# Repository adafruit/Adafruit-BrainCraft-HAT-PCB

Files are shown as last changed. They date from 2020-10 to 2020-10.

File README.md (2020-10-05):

## Adafruit Adafruit BrainCraft HAT - Machine Learning for Raspberry Pi 4 PCB

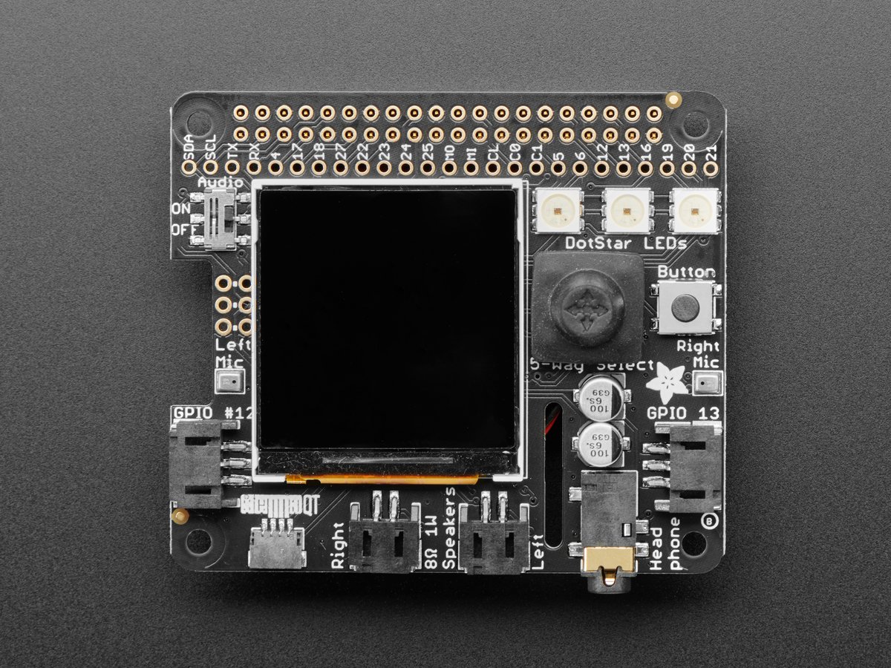
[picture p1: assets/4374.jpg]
<a href="http://www.adafruit.com/products/4374"><br/>
Click here to purchase one from the Adafruit shop</a>

PCB files for the Adafruit BrainCraft HAT - Machine Learning for Raspberry Pi 4. 

Format is EagleCAD schematic and board layout
* https://www.adafruit.com/product/4374

### Description

The idea behind the BrainCraft HAT is that you’d be able to “craft brains” for Machine Learning on the EDGE, with Microcontrollers & Microcomputers. On ASK AN ENGINEER, our founder & engineer chatted with Pete Warden, the technical lead of the mobile, embedded TensorFlow Group on Google’s Brain team about what would be ideal for a board like this.

And here’s what we designed! The BrainCraft HAT has a 240×240 TFT IPS display for inference output, slots for camera connector cable for imaging projects, a 5 way joystick and button for UI input, left and right microphones, stereo headphone out, stereo 1 W speaker out, three RGB DotStar LEDs, two 3 pin STEMMA connectors on PWM pins so they can drive NeoPixels or servos, and Grove/STEMMA/Qwiic I2C port. This will let people build a wide range of audio/video AI projects while also allowing easy plug-in of sensors and robotics!

A controllable mini fan attaches to the bottom, and can be used to keep your Pi cool while doing intense AI inference calculations. **Most importantly, there’s an On/Off switch that will completely disable the audio codec, so that when it's off there’s no way it's listening to you.**

**Features:**
 * **1.54" IPS TFT** display with 240x240 resolution that can show text or video
 * **Stereo speaker ports for audio playback** - either text-to-speech, alerts or for creating a voice assistant.
 * **Stereo headphone out** for audio playback through a stereo system, headphones, or powered speakers.
 * **Stereo microphone input** - perfect for making your very own smart home assistants
 * **Two 3-pin JST STEMMA connectors** that can be used to [connect more buttons](https://www.adafruit.com/product/4431), [a relay](https://www.adafruit.com/product/4409), or [even some NeoPixels!](https://www.adafruit.com/product/3919)
 * **[STEMMA QT plug-and-play I2C port](https://learn.adafruit.com/introducing-adafruit-stemma-qt)**, can be used with [any of our 50+ I2C STEMMA QT boards](https://www.adafruit.com/category/620), or can be used to [connect to Grove I2C devices with an adapter cable](https://www.adafruit.com/product/4528).
 * **5-Way Joystick + Button** for user interface and control.
 * **Three RGB DotStar LEDs** for colorful LED feedback.

The STEMMA QT port means you can attach heat image sensors like the [Panasonic Grid-EYE](https://www.adafruit.com/product/3538) or [MLX90640](https://www.adafruit.com/?q=mlx90640&sort=BestMatch). Heat-Sensitive cameras can be used as a person detector, even in the dark! An external accelerometer can be attached for gesture or vibration sensing such as machinery/industrial predictive maintenance projects

### License

Adafruit invests time and resources providing this open source design, please support Adafruit and open-source hardware by purchasing products from [Adafruit](https://www.adafruit.com)!

Designed by Limor Fried/Ladyada for Adafruit Industries.

Creative Commons Attribution/Share-Alike, all text above must be included in any redistribution. 
See license.txt for additional details.

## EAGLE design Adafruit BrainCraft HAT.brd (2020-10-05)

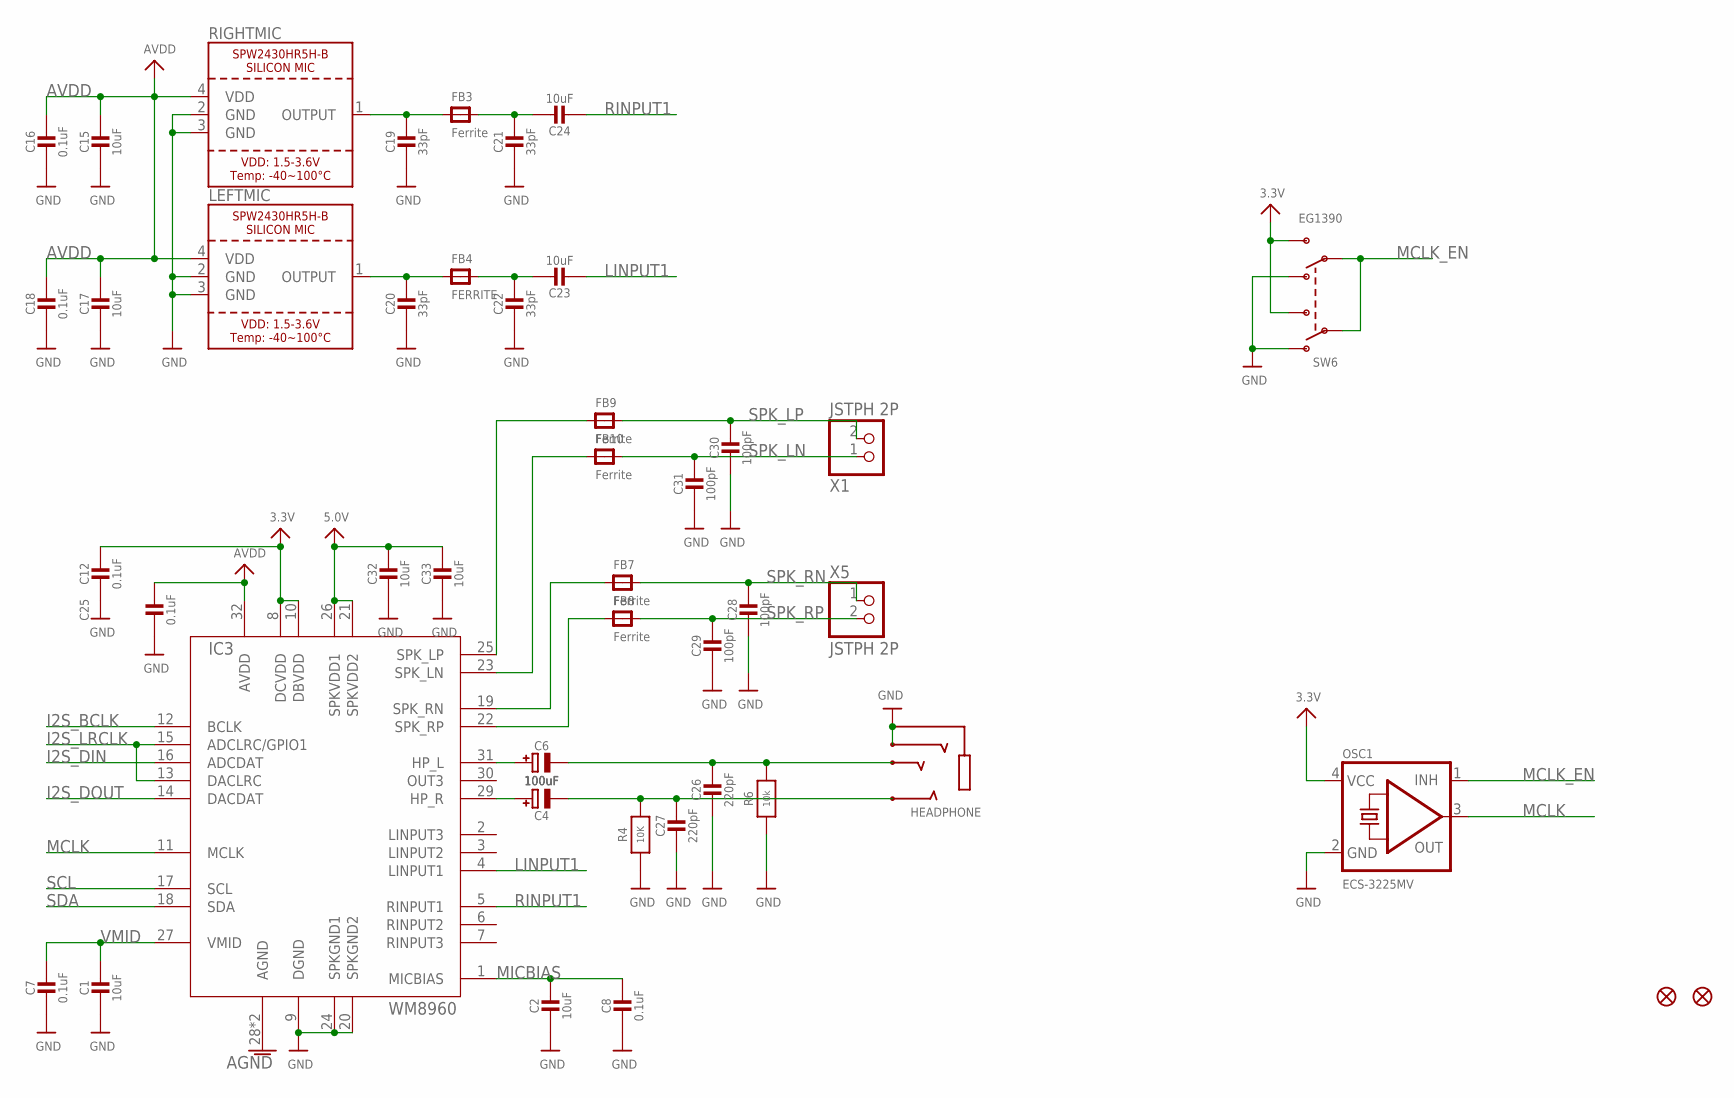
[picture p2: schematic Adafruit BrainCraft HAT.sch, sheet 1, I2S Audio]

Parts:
C1, C2, C15, C17, C23, C24, C32, C33: 10uF; 0805-NO
C4, C6: 100uF; PANASONIC_C
C7, C8, C12, C16, C18, C25: 0.1uF; 0603-NO
C19, C20, C21, C22: 33pF; 0603-NO
C26, C27: 220pF; 0603-NO
C28, C29, C30, C31: 100pF; 0603-NO
FB3, FB7, FB8, FB9, FB10: Ferrite; 0805-NO
FB4: FERRITE; 0805-NO
FID1, FID2: FIDUCIAL_1MM
HEADPHONE: AUDIO_3.5MMJACK_4POL; 4UCONN_18510
IC3: WM8960; QFN32_5MM
LEFTMIC: SPW2430HR5H-B
OSC1: ECS-3225MV; OSC_3.2X2.5MM
R4: 10K; 0603-NO
R6: 10k; 0603-NO
RIGHTMIC: SPW2430HR5H-B
SW6: EG1390
X1, X5: JSTPH 2P; JSTPH2

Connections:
3.3V: C12.1, IC3.8 (DCVDD), IC3.10 (DBVDD), OSC1.4 (VCC), SW6.S1, SW6.S2; also elsewhere on the board
5.0V: C32.1, C33.1, IC3.21 (SPKVDD2), IC3.26 (SPKVDD1); also elsewhere on the board
AGND: IC3.28 (AGND), IC3.33 (AGND); also elsewhere on the board
AVDD: C15.1, C16.1, C17.1, C18.1, C25.1, IC3.32 (AVDD), LEFTMIC.4 (VDD), RIGHTMIC.4 (VDD); also elsewhere on the board
GND: C1.2, C2.2, C7.2, C8.2, C12.2, C15.2, C16.2, C17.2, C18.2, C19.2, C20.2, C21.2, C22.2, C25.2, C26.2, C27.2, C28.2, C29.2, C30.2, C31.2, C32.2, C33.2, HEADPHONE.1-GND (TIP), HEADPHONE.4-INNER_SLEEVE (RING1), IC3.9 (DGND), IC3.20 (SPKGND2), IC3.24 (SPKGND1), LEFTMIC.2 (GND), LEFTMIC.3 (GND), OSC1.2 (GND), R4.1, R6.1, RIGHTMIC.2 (GND), RIGHTMIC.3 (GND), SW6.O1, SW6.O2; also elsewhere on the board
I2S_BCLK: IC3.12 (BCLK); also elsewhere on the board
I2S_DIN: IC3.16 (ADCDAT); also elsewhere on the board
I2S_DOUT: IC3.14 (DACDAT); also elsewhere on the board
I2S_LRCLK: IC3.13 (DACLRC), IC3.15 (ADCLRC/GPIO1); also elsewhere on the board
LINPUT1: C23.2, IC3.4 (LINPUT1)
MCLK: IC3.11 (MCLK), OSC1.3 (OUT)
MCLK_EN: OSC1.1 (INH), SW6.P1, SW6.P2
MICBIAS: C2.1, C8.1, IC3.1 (MICBIAS)
unnamed: FB7.1, IC3.19 (SPK_RN)
unnamed: FB8.1, IC3.22 (SPK_RP)
unnamed: C6.+, IC3.31 (HP_L)
unnamed: C4.+, IC3.29 (HP_R)
unnamed: C4.-, C27.1, HEADPHONE.3-OUTER_SLEEVE (RING2), R4.2
unnamed: C6.-, C26.1, HEADPHONE.2-TIP (RING3), R6.2
unnamed: C19.1, FB3.1, RIGHTMIC.1 (OUTPUT)
unnamed: C20.1, FB4.1, LEFTMIC.1 (OUTPUT)
unnamed: C21.1, C24.1, FB3.2
unnamed: C22.1, C23.1, FB4.2
unnamed: FB9.1, IC3.25 (SPK_LP)
unnamed: FB10.1, IC3.23 (SPK_LN)
RINPUT1: C24.2, IC3.5 (RINPUT1)
SCL: IC3.17 (SCL); also elsewhere on the board
SDA: IC3.18 (SDA); also elsewhere on the board
SPK_LN: C31.1, FB10.2, X1.1
SPK_LP: C30.1, FB9.2, X1.2
SPK_RN: C28.1, FB7.2, X5.1
SPK_RP: C29.1, FB8.2, X5.2
VMID: C1.1, C7.1, IC3.27 (VMID)

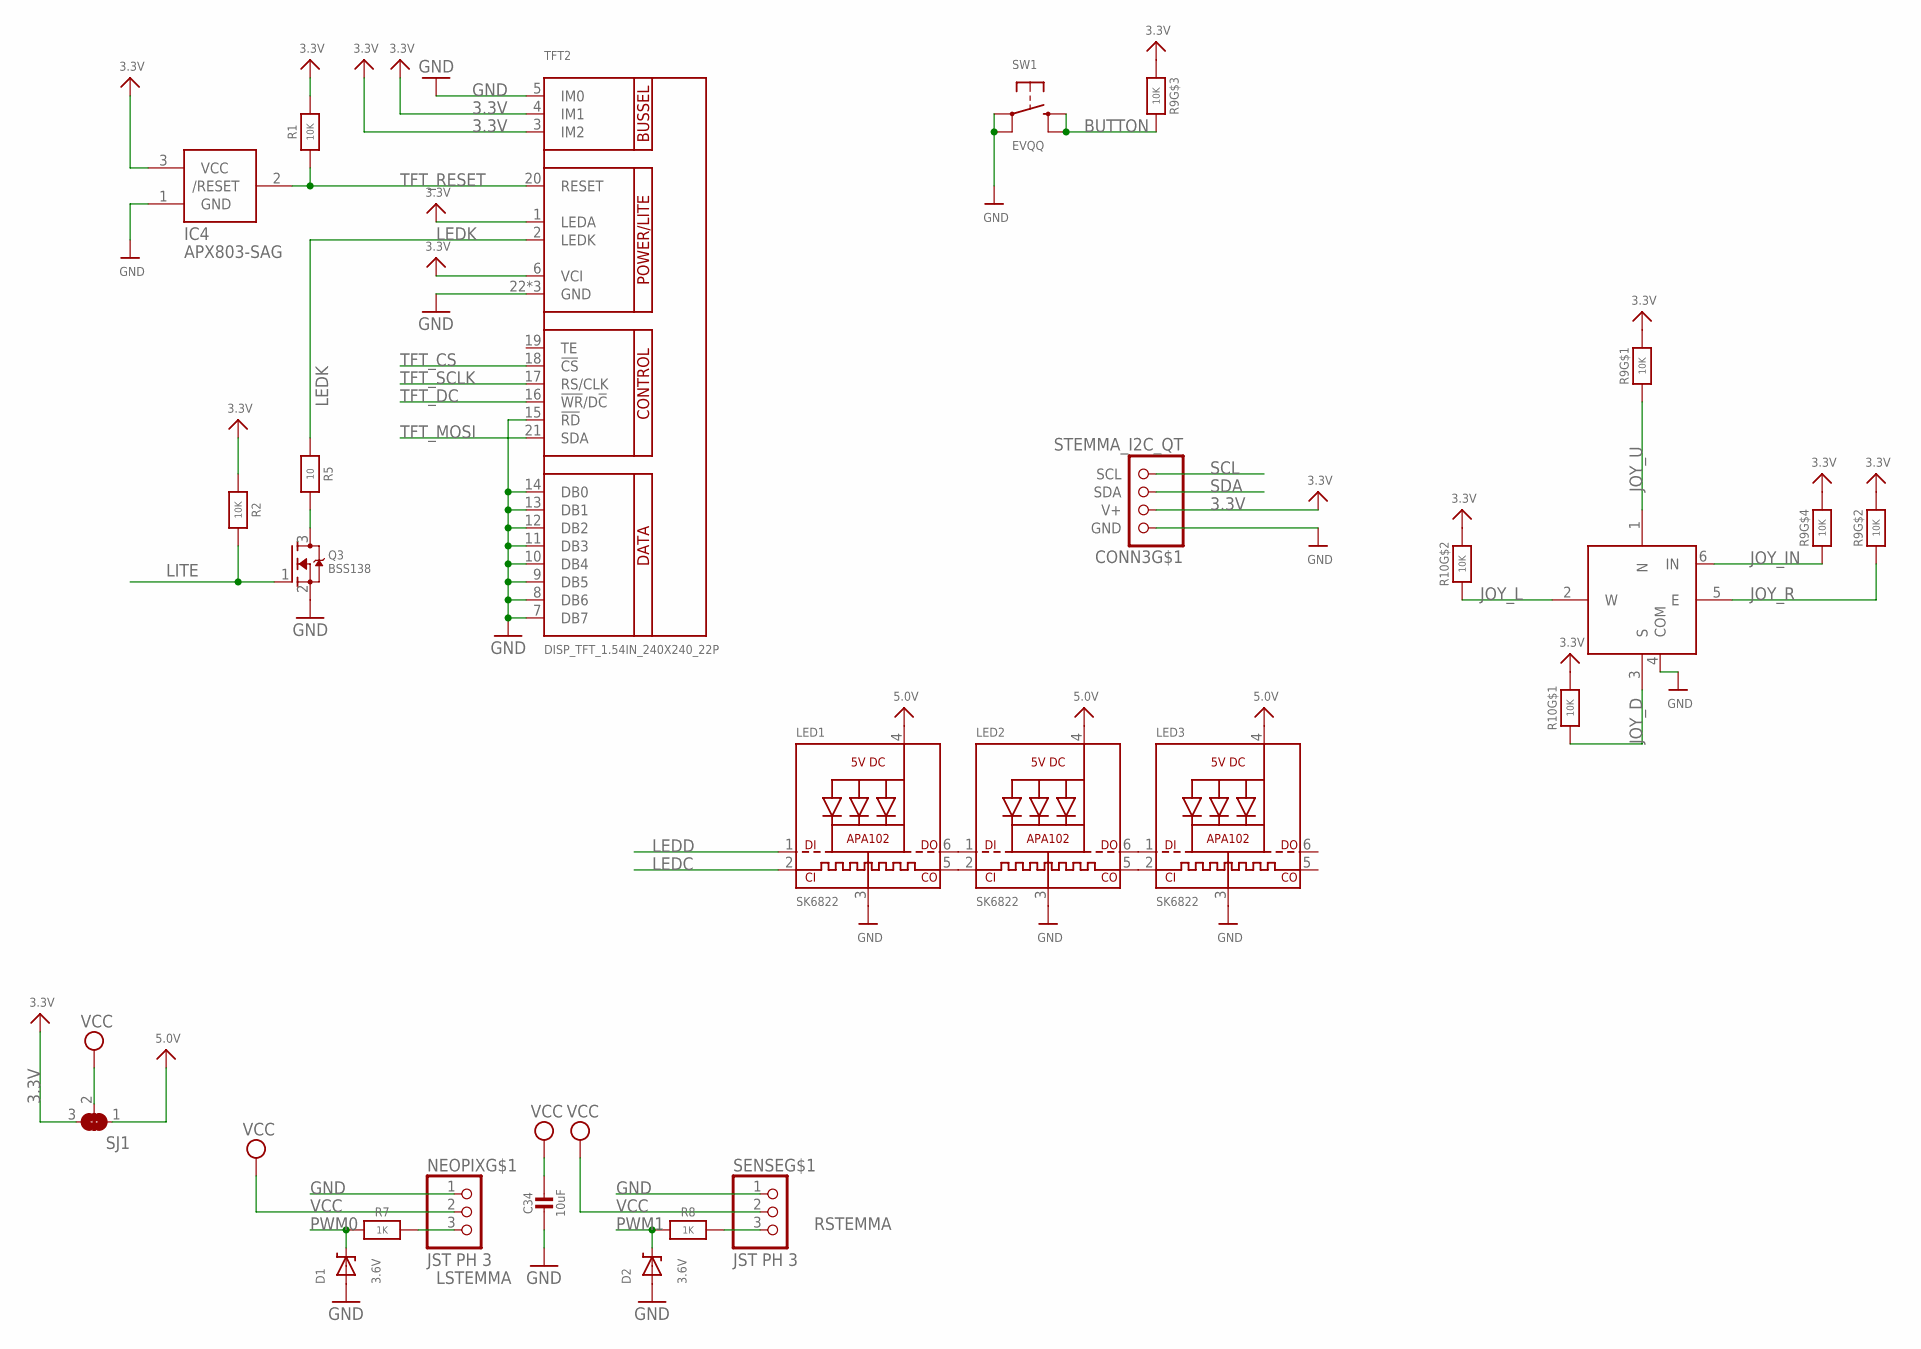
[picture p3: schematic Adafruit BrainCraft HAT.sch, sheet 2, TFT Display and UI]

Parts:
C34: 10uF; 0805-NO
CONN3: STEMMA_I2C_QT; JST_SH4
D1, D2: 3.6V; SOD-323
IC4: APX803-SAG; SOT23
LED1, LED2, LED3: SK6822; APA102
NEOPIX: JST PH 3; JSTPH3
Q3: BSS138; SOT23-WIDE
R1, R2: 10K; 0603-NO
R5: 10; 0603-NO
R7, R8: 1K; 0603-NO
R9, R10: 10K; RESPACK_4X0603
SENSE: JST PH 3; JSTPH3
SJ1: SOLDERJUMPER_2WAY; SOLDERJUMPER_2WAY_OPEN_NOPASTE
SW1: EVQQ; EVQ-Q2_SMALLER
SW5: NAVSWITCHSKQUABAUE010; SKQUBAE010
TFT2: DISP_TFT_1.54IN_240X240_22P; TFT_1.54IN_240X240_22PIN

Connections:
3.3V: CONN3.2 (V+), IC4.3 (VCC), R1.2, R2.2, R9.5 (2), R9.6 (2), R9.7 (2), R9.8 (2), R10.7 (2), R10.8 (2), SJ1.3, TFT2.1 (LEDA), TFT2.3 (IM2), TFT2.4 (IM1), TFT2.6 (VCI); also elsewhere on the board
5.0V: LED1.4 (VDD), LED2.4 (VDD), LED3.4 (VDD), SJ1.1; also elsewhere on the board
BUTTON: R9.3 (1), SW1.B (S), SW1.B' (S1); also elsewhere on the board
GND: C34.2, CONN3.1 (GND), D1.A, D2.A, IC4.1 (GND), LED1.3 (GND), LED2.3 (GND), LED3.3 (GND), NEOPIX.1, Q3.2 (S), SENSE.1, SW1.A, SW1.A' (P1), SW5.4 (COM), TFT2.5 (IM0), TFT2.7 (DB7), TFT2.8 (DB6), TFT2.9 (DB5), TFT2.10 (DB4), TFT2.11 (DB3), TFT2.12 (DB2), TFT2.13 (DB1), TFT2.14 (DB0), TFT2.15 (!RD), TFT2.22 (GND), TFT2.SUPPORT1 (GND), TFT2.SUPPORT2 (GND); also elsewhere on the board
JOY_D: R10.1, SW5.3 (S); also elsewhere on the board
JOY_IN: R9.4 (1), SW5.6 (IN); also elsewhere on the board
JOY_L: R10.2 (1), SW5.2 (W); also elsewhere on the board
JOY_R: R9.2 (1), SW5.5 (E); also elsewhere on the board
JOY_U: R9.1, SW5.1 (N); also elsewhere on the board
LEDC: LED1.2 (CKI); also elsewhere on the board
LEDD: LED1.1 (DI); also elsewhere on the board
LEDK: R5.2, TFT2.2 (LEDK)
LITE: Q3.1 (G), R2.1; also elsewhere on the board
LSTEMMA: NEOPIX.3, R7.1
unnamed: Q3.3 (D), R5.1
unnamed: LED1.6 (DO), LED2.1 (DI)
unnamed: LED1.5 (CKO), LED2.2 (CKI)
unnamed: LED2.6 (DO), LED3.1 (DI)
unnamed: LED2.5 (CKO), LED3.2 (CKI)
PWM0: D1.C, R7.2; also elsewhere on the board
PWM1: D2.C, R8.2; also elsewhere on the board
RSTEMMA: R8.1, SENSE.3
SCL: CONN3.4 (SCL); also elsewhere on the board
SDA: CONN3.3 (SDA); also elsewhere on the board
TFT_CS: TFT2.18 (!CS); also elsewhere on the board
TFT_DC: TFT2.16 (!WR!/D!C); also elsewhere on the board
TFT_MOSI: TFT2.21 (SDA); also elsewhere on the board
TFT_RESET: IC4.2 (/RESET), R1.1, TFT2.20 (RESET)
TFT_SCLK: TFT2.17 (RS/CLK); also elsewhere on the board
VCC: C34.1, NEOPIX.2, SENSE.2, SJ1.2

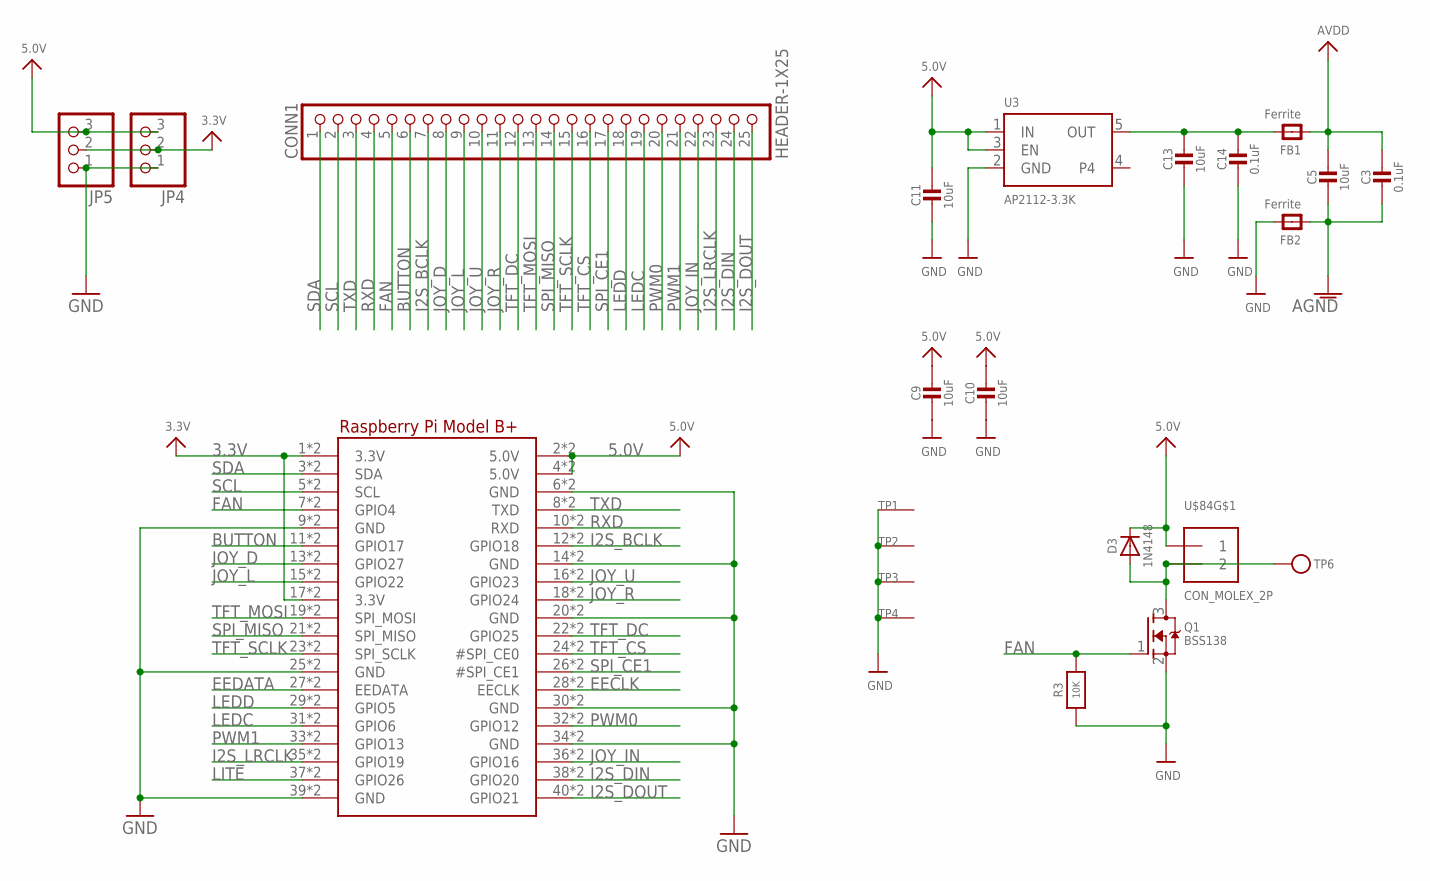
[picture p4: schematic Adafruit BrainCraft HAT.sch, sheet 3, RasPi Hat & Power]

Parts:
C3, C14: 0.1uF; 0603-NO
C5, C9, C10, C11, C13: 10uF; 0805-NO
CONN1: HEADER-1X25; 1X25_ROUND_70MIL
D3: 1N4148; SOD-323
FB1, FB2: Ferrite; 0805
JP4, JP5: HEADER-1X376MIL; 1X03_ROUND_76
Q1: BSS138; SOT23-WIDE
R3: 10K; 0603-NO
RPI1: RASPBERRYPI_BPLUS_HAT_SMTTHM_SLOTS; PI_HAT_SMTTHM_SLOTS
TP1, TP2, TP3, TP4: SEWTAP_SMTNUTM3; SMT_NUT_3MM
TP6: TESTPOINTROUND2MM; TESTPOINT_ROUND_2MM
U3: AP2112-3.3K; SOT23-5
U$84: CON_MOLEX_2P; 53398-0271

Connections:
3.3V: JP4.2, JP5.2, RPI1.1 (3.3V), RPI1.17 (3.3V), RPI1.S1 (3.3V), RPI1.S17 (3.3V); also elsewhere on the board
5.0V: C9.1, C10.1, C11.1, D3.C, JP4.3, JP5.3, RPI1.2 (5.0V), RPI1.4 (5.0V), RPI1.S2 (5.0V), RPI1.S4 (5.0V), U3.1 (IN), U3.3 (EN), U$84.1; also elsewhere on the board
AGND: C3.2, C5.2, FB2.1; also elsewhere on the board
AVDD: C3.1, C5.1, FB1.1; also elsewhere on the board
BUTTON: CONN1.6, RPI1.11 (GPIO17), RPI1.S11 (GPIO17); also elsewhere on the board
EECLK: RPI1.28 (EECLK), RPI1.S28 (EECLK)
EEDATA: RPI1.27 (EEDATA), RPI1.S27 (EEDATA)
FAN: CONN1.5, Q1.1 (G), R3.1, RPI1.7 (GPIO4), RPI1.S7 (GPIO4)
GND: C9.2, C10.2, C11.2, C13.2, C14.2, FB2.2, JP4.1, JP5.1, Q1.2 (S), R3.2, RPI1.6 (GND), RPI1.9 (GND), RPI1.14 (GND), RPI1.20 (GND), RPI1.25 (GND), RPI1.30 (GND), RPI1.34 (GND), RPI1.39 (GND), RPI1.S6 (GND), RPI1.S9 (GND), RPI1.S14 (GND), RPI1.S20 (GND), RPI1.S25 (GND), RPI1.S30 (GND), RPI1.S34 (GND), RPI1.S39 (GND), TP1.P$1, TP2.P$1, TP3.P$1, TP4.P$1, U3.2 (GND); also elsewhere on the board
I2S_BCLK: CONN1.7, RPI1.12 (GPIO18), RPI1.S12 (GPIO18); also elsewhere on the board
I2S_DIN: CONN1.24, RPI1.38 (GPIO20), RPI1.S38 (GPIO20); also elsewhere on the board
I2S_DOUT: CONN1.25, RPI1.40 (GPIO21), RPI1.S40 (GPIO21); also elsewhere on the board
I2S_LRCLK: CONN1.23, RPI1.35 (GPIO19), RPI1.S35 (GPIO19); also elsewhere on the board
JOY_D: CONN1.8, RPI1.13 (GPIO27), RPI1.S13 (GPIO27); also elsewhere on the board
JOY_IN: CONN1.22, RPI1.36 (GPIO16), RPI1.S36 (GPIO16); also elsewhere on the board
JOY_L: CONN1.9, RPI1.15 (GPIO22), RPI1.S15 (GPIO22); also elsewhere on the board
JOY_R: CONN1.11, RPI1.18 (GPIO24), RPI1.S18 (GPIO24); also elsewhere on the board
JOY_U: CONN1.10, RPI1.16 (GPIO23), RPI1.S16 (GPIO23); also elsewhere on the board
LEDC: CONN1.19, RPI1.31 (GPIO6), RPI1.S31 (GPIO6); also elsewhere on the board
LEDD: CONN1.18, RPI1.29 (GPIO5), RPI1.S29 (GPIO5); also elsewhere on the board
LITE: RPI1.37 (GPIO26), RPI1.S37 (GPIO26); also elsewhere on the board
unnamed: D3.A, Q1.3 (D), TP6.P$1, U$84.2
OUT: C13.1, C14.1, FB1.2, U3.5 (OUT)
PWM0: CONN1.20, RPI1.32 (GPIO12), RPI1.S32 (GPIO12); also elsewhere on the board
PWM1: CONN1.21, RPI1.33 (GPIO13), RPI1.S33 (GPIO13); also elsewhere on the board
RXD: CONN1.4, RPI1.10 (RXD), RPI1.S10 (RXD)
SCL: CONN1.2, RPI1.5 (SCL), RPI1.S5 (SCL); also elsewhere on the board
SDA: CONN1.1, RPI1.3 (SDA), RPI1.S3 (SDA); also elsewhere on the board
SPI_CE1: CONN1.17, RPI1.26 (#SPI_CE1), RPI1.S26 (#SPI_CE1)
SPI_MISO: CONN1.14, RPI1.21 (SPI_MISO), RPI1.S21 (SPI_MISO)
TFT_CS: CONN1.16, RPI1.24 (#SPI_CE0), RPI1.S24 (#SPI_CE0); also elsewhere on the board
TFT_DC: CONN1.12, RPI1.22 (GPIO25), RPI1.S22 (GPIO25); also elsewhere on the board
TFT_MOSI: CONN1.13, RPI1.19 (SPI_MOSI), RPI1.S19 (SPI_MOSI); also elsewhere on the board
TFT_SCLK: CONN1.15, RPI1.23 (SPI_SCLK), RPI1.S23 (SPI_SCLK); also elsewhere on the board
TXD: CONN1.3, RPI1.8 (TXD), RPI1.S8 (TXD)

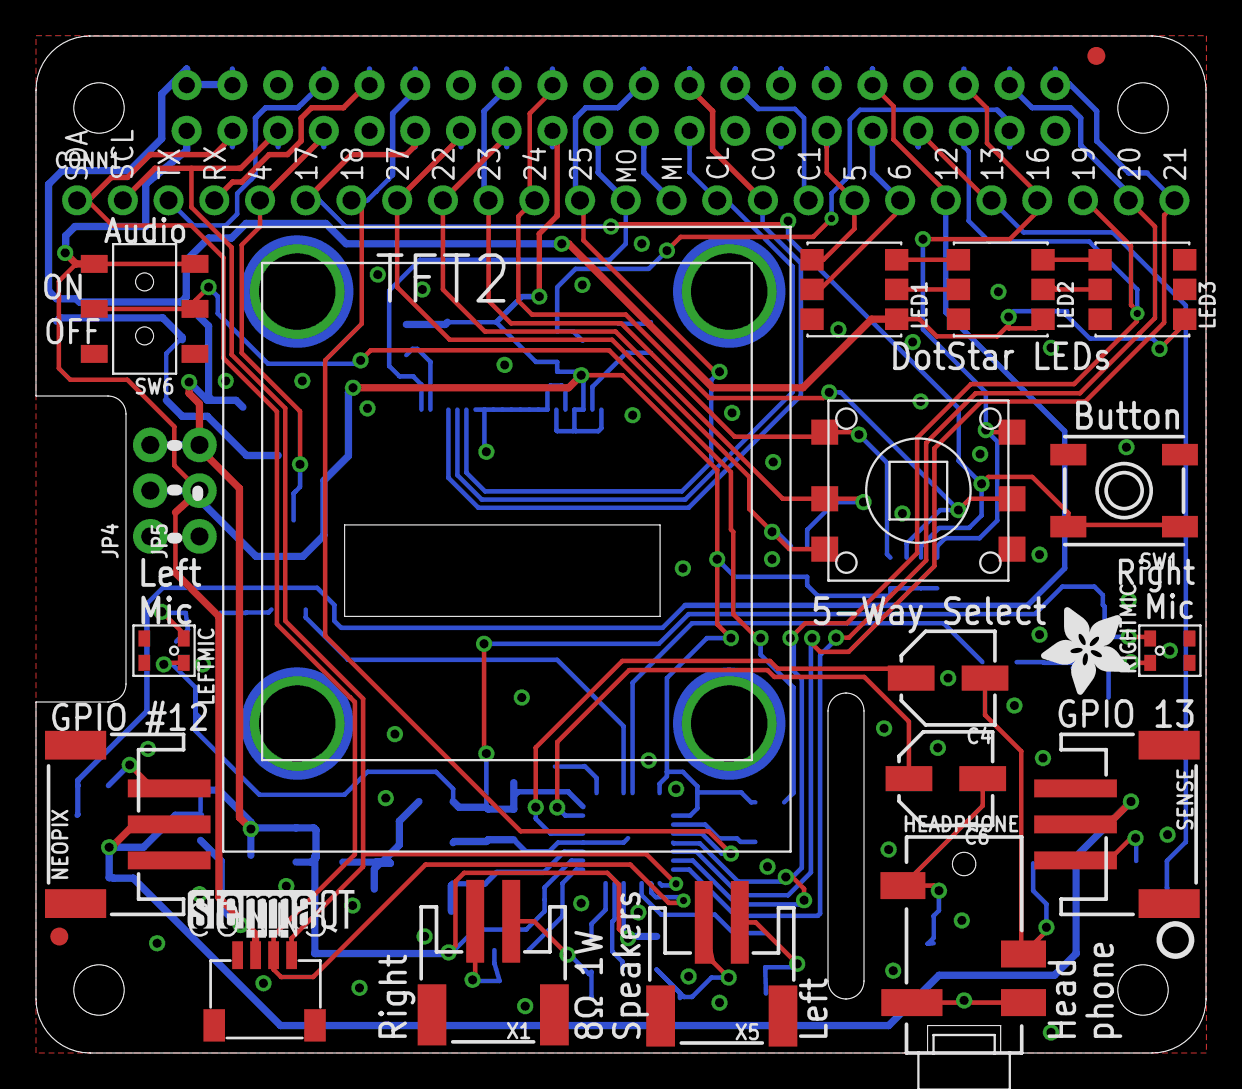
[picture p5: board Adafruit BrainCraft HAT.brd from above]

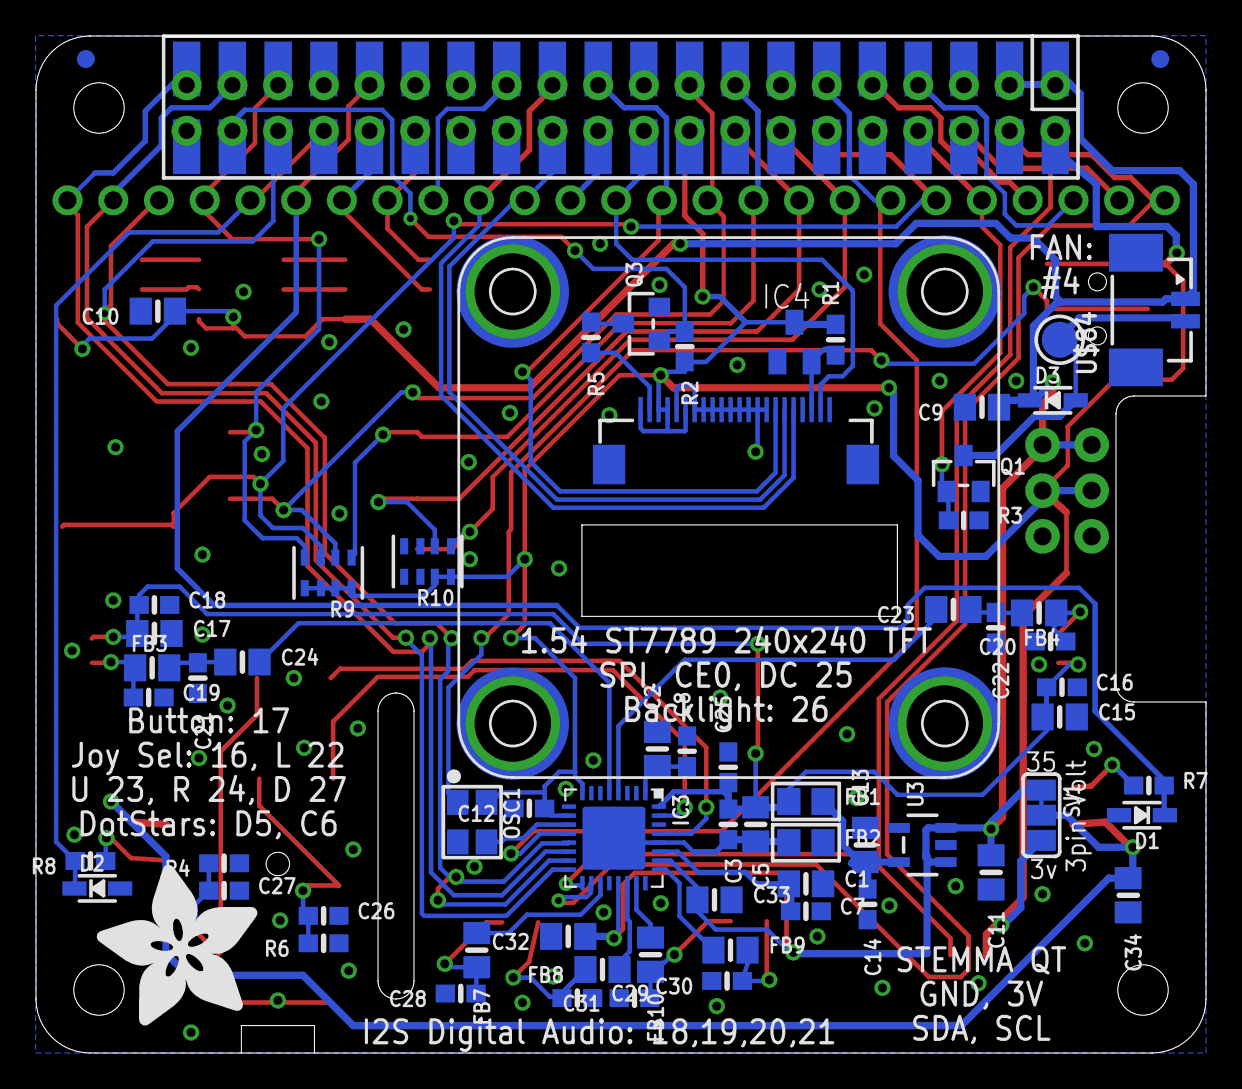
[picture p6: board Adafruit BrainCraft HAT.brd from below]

Board: 2 copper layers, 65.0 x 56.5 mm, 95 parts (69 on the bottom side), 67 nets.

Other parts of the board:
U$11: PCBFEAT-REV-040
U$72: STEMMAQT
U$75: ADAFRUIT_5MM
U$79: BRAINPAD_1IN
U$82: FAN_30X30MM
U$87: ADAFRUIT_9MM

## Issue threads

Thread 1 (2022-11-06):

BrainCraft does not turn off when you shut down the underlying operating system

eqikkwkp25-cyber, 2022-11-06:
Hello,

first: Many thanks for designing this HAT. Looks like i am the first one to open an issue and hope its the right place and official repository.

I use the board on top of a Raspberry Pi Zero 2 W. When i shut down the underlying operating system (latest Raspian buster) the back light of BrainCraft is still active. Why and how does this work and for which purpose?

Thanks.

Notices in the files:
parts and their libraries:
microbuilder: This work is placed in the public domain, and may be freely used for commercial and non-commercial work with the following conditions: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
